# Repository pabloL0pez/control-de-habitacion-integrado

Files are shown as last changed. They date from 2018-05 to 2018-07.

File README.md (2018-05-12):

# Control de habitación integrado

## Hardware

* Modulo rfid: RFID-RC522 $60.45 x2
* Arduino nano
* Sensor de luz ldr
* Sensor de movimiento: Modulo PIR HC-SR501 $56.68
* Modulo wifi: esp8266 $108
* Boozer piezoelectrico
* Fotoresistencia LDR
* Sensor magnetico
* Pulsador
* tags rfid
* rele (para simular desbloqueo de puerta)

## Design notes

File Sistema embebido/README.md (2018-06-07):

# Control de habitación integrado - Arduino

## Hardware

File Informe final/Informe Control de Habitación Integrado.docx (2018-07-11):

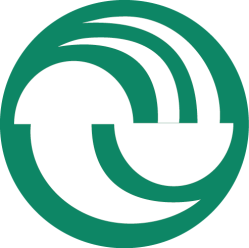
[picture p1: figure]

Universidad Nacional de La Matanza

Departamento de Ingeniería e Investigaciones Tecnológicas

Sistemas Operativos Avanzados

Trabajo Práctico

Sistemas Embebidos Android

Control de Habitación Integrado

Apellido y Nombre | DNI
Beckerman, Leandro | 34295624
López, Pablo Joel | 39154213
Fritz, Braian Nicolas | 38130321
De Diego, Brian Adrián | 36399037

# Descripción General

Este sistema permite la apertura de puertas a través de tarjetas magnéticas que al apoyarlas en un lector colocado al lado de cada puerta, verifica que la tarjeta esté autorizada para poder abrirla. Además, permite otras funcionalidades mediante una aplicación de celular como la apertura de puerta sin tarjeta, control de encendido, apagado e intensidad de luz de la misma, corroborar si hay gente dentro de ella y adicionalmente poder medir la cantidad de luz.

# Objetivo

El objetivo del Proyecto es la apertura de puertas a través de un módulo RFID, se realiza la validación de la clave de la tarjeta a través de un web service y desbloquea la misma. Una vez que se abren las puertas se captura un log de información de la persona que quiere ingresar al establecimiento. Paralelamente se puede controlar la luz de la habitación mediante una aplicación para Android, ver el estado de la habitación que se comunica con el mismo web service mediante JSON.

# Consideraciones

- Detectar cuando la puerta está abierta/cerrada.
- Detectar cuando hay individuos en la sala
- Si la puerta no se cierra o no está bien cerrada, entonces el sistema debe emitir un sonido de advertencia durante un determinado tiempo.
  - Si la puerta se cierra correctamente se apaga el sonido de advertencia.
  - Si durante ese tiempo no se cierra la puerta, entonces se apaga tal sonido. (Evitar que sea molesto)
- La persona puede encender o modificar (intensidad de luz) de las luces del establecimiento.
- Al fallar la identificación de la tarjeta N veces, se toma una advertencia (posible bloqueo).

Los fundamentos principales del Proyecto constan:

- Permitir el acceso a personas autorizadas hacía un lugar restringido. Guardar la información de las tarjetas (IDs) de las personas que ingresan al establecimiento.
- Identificación de intrusos.
- Aplicable a lugares donde hay un acceso restringido.

# Diagrama Físico

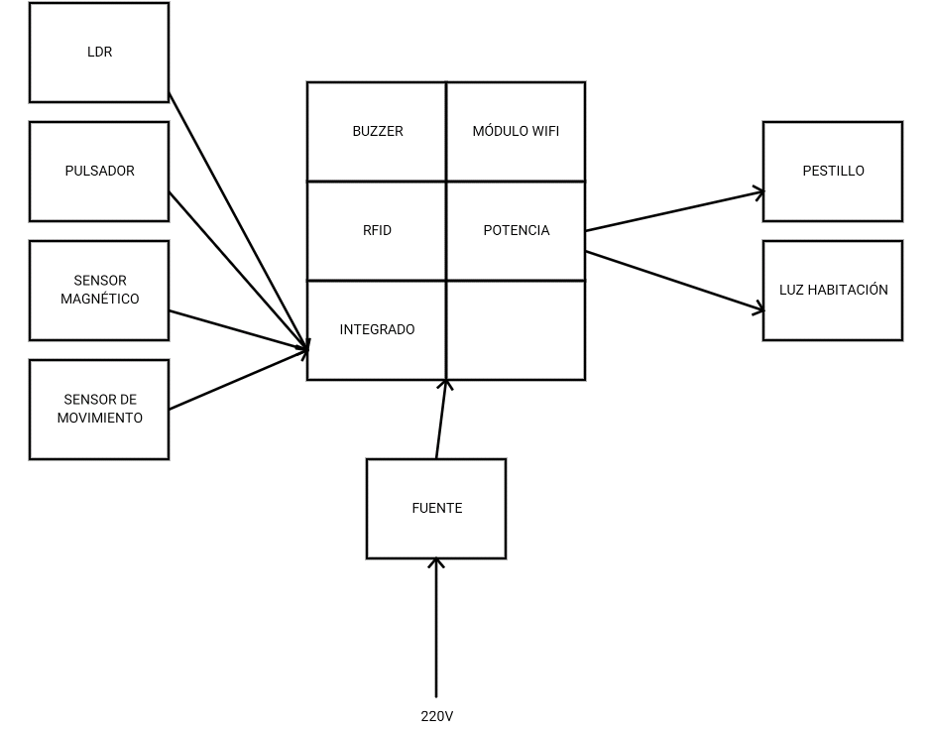
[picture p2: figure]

# Diagrama Lógico

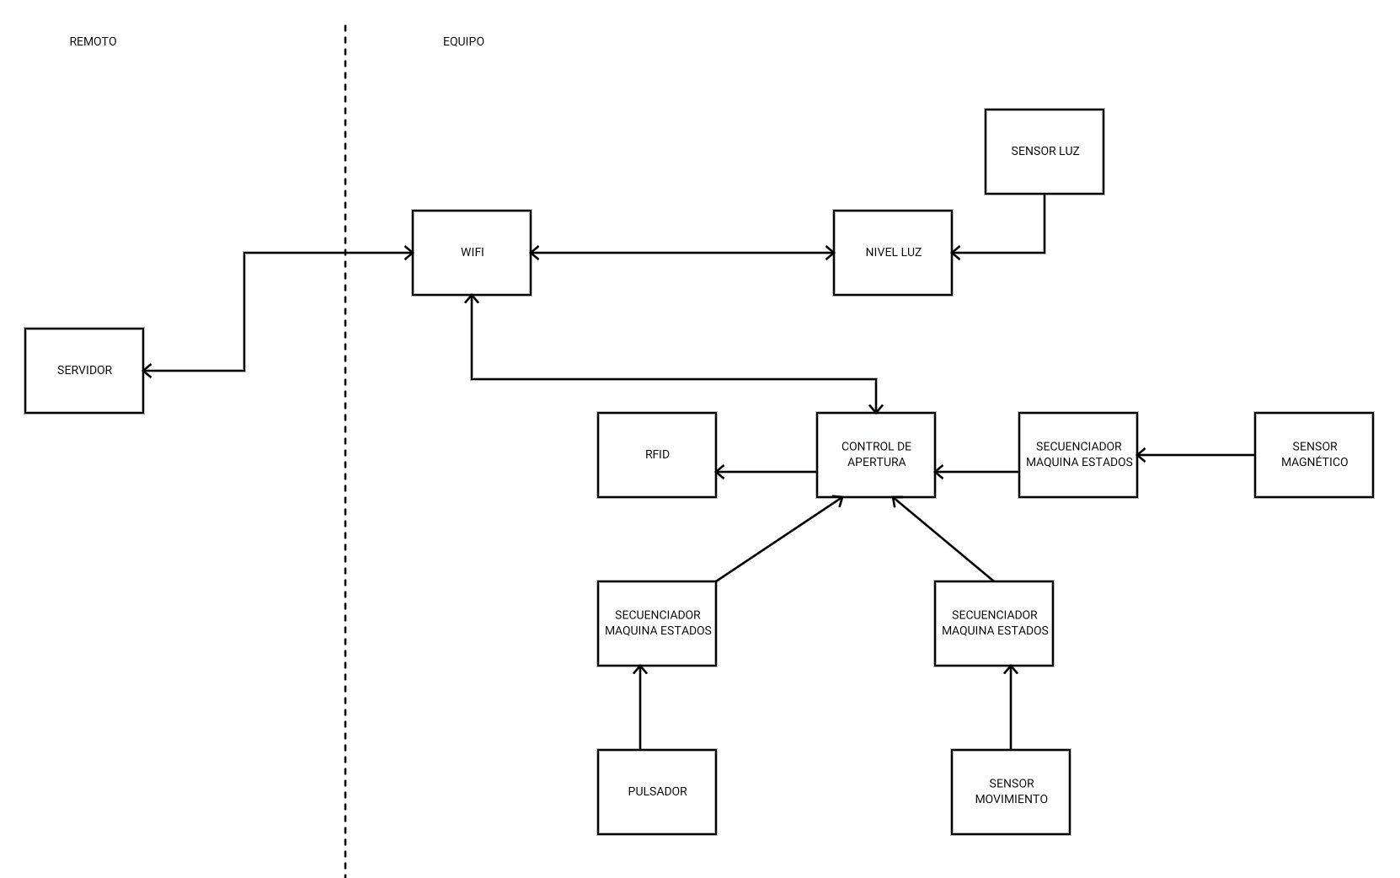
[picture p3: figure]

# Circuito Esquemático

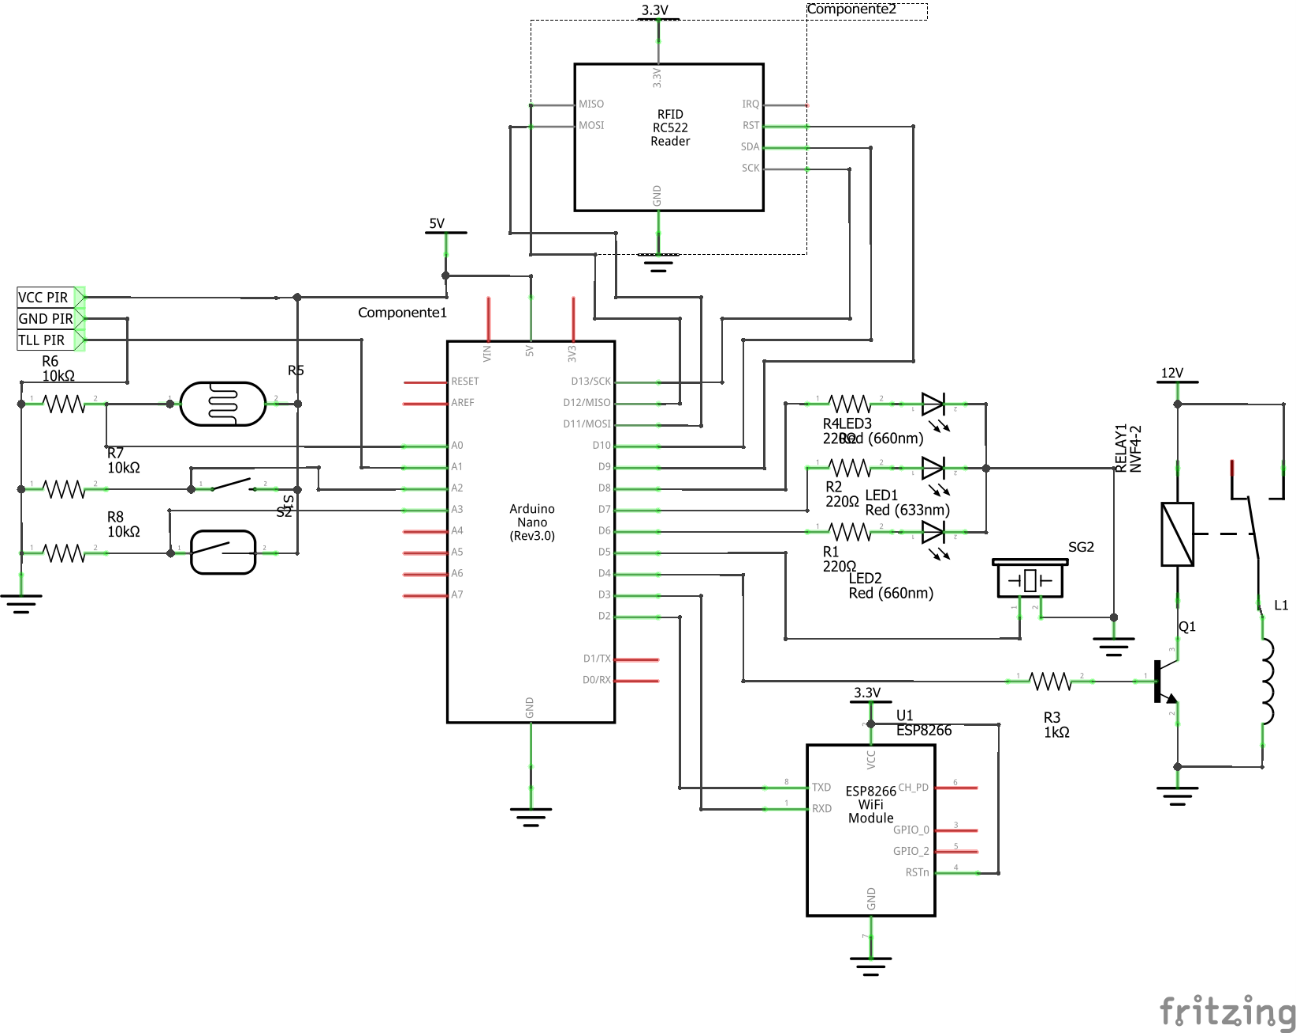
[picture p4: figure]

# Hardware utilizado

Módulo RFID-RC522 | Buzzer piezoeléctrico
Arduino NANO V3 | LEDs
Fotorresistor LDR | Sensor magnético
Modulo PIR HC-SR501 | Pulsador
Módulo WiFi ESP8266-01 | Tags RFID
Rele | Transitor NPN BC548
Pestillo eléctrico | 2 ProtoBoard de 150 puntos
Resistencias | Cables de Conexion

# Software utilizado

- Android Studio 2.3
- Arduino IDE 1.8.2
- Servidor Web NodeJS versión 8

# Tareas realizadas

1. Se realizo un diagrama de conexión y se procedio a conectar todos los componentes descritos en el hardware al Arduino
2. Se programo en Arduino IDE el sketch para automatizar el sistema y poder permitir la comunicación de la lógica de la habitación con el servidor mediante el modulo WiFi
3. Desarrollamos un web service en NodeJS para ser la interfaz entre el Arduino y la aplicación de celulares, además de ser el encargado de determinar cuando una tarjeta es válida o no
4. Desarrollamos una aplicación para Android con el fin de poder hacer desde ella un control total de todas las funciones del sistema, como la apertura de puerta sin tarjeta, control de intensidad lumínica de la habitación, ver registro de entradas y salidas, etc.

# Información técnica

## Módulo RFID RC522

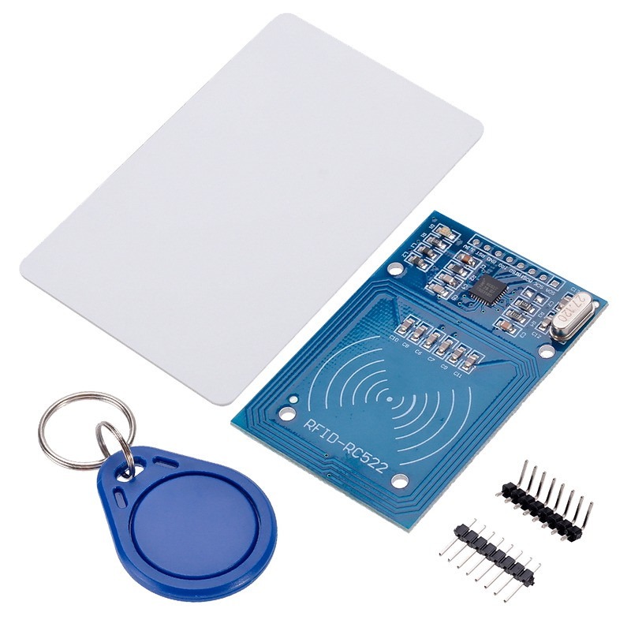
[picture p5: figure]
Resultado de imagen para tarjetas rfid

Su principio de funcionamiento consiste en pasar un TAG, cerca de un lector RFID, el TAG tiene la capacidad de enviar información al lector. Dicha información puede ser desde un simple código o todo un paquete de información guardo en la memoria del Tag.

Los TAGs viene en diferentes modelos, los más comunes son en tarjetas y en llaveros, pero también vienen como etiquetas adhesivas e incluso ya viene incrustados en algunos productos. Los Tags tienen internamente una antena y un microchip, encargado de realizar todo el proceso de comunicación, la energía lo obtiene de la señal de radiofrecuencia, que si bien la energía en la señal es pequeña, es suficiente para hacer trabajar el microchip, esto es la razón por la que es necesario acercarlos a una pequeña distancia generalmente menor a 10 cm.

## Buzzer piezoeléctrico

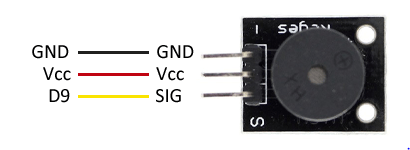
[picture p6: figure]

Los buzzer son transductores piezoeléctricos. Los materiales piezoeléctricos tienen la propiedad especial de variar su volumen al ser atravesados por corrientes eléctricas. Un buzzer aprovecha este fenómeno para hacer vibrar una membrana al atravesar el material piezoeléctrico con una señal eléctrica. Los buzzer son dispositivos pequeños y compactos, con alta durabilidad, y bajo consumo eléctrico.

## Arduino Nano V3

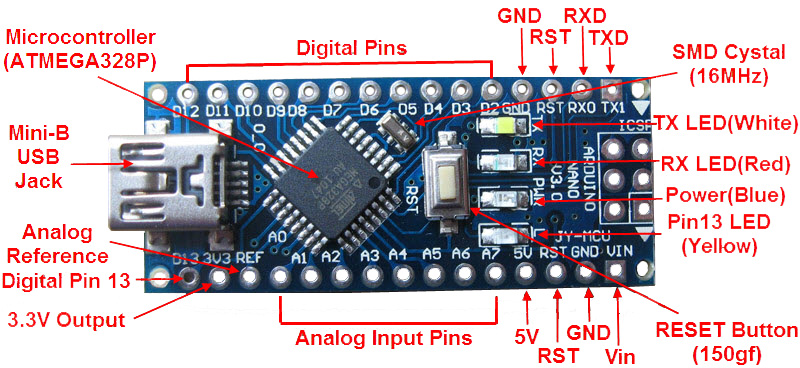
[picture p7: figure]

Este Arduino es la versión mas pequeña del Arduino uno. Basada en el Atmega328 SMD. Esta version esta pensada para usar en protoboard. las disposicion de sus pines facilitan la conexion de los componentes si necesidad de muchos cables. La otra gran ventaja por mas obvia que parezca esta en su tamao, durante algun tiempo fue la placa mas pequeña de todas, luego superada por el Arduino Micro(basada en el chip del leonardo) y el Arduino Mini Pro(basado tambien en el Atmega328).

## Sensor de movimiento PIR HC-SR501

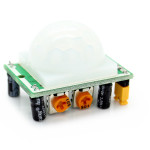
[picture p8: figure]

El módulo HC-SR501 tiene 3 pines de conexión +5v, OUT (3,3v) y GND, y dos resistencias variables de calibración (Ch1 y RL2).

Los detectores PIR (Passive Infrared) o Pasivo Infrarrojo, reaccionan sólo ante determinadas fuentes de energía tales como el calor del cuerpo humano o animales. Básicamente reciben la variación de las radiaciones infrarrojas del medio ambiente que cubre. Es llamado pasivo debido a que no emite radiaciones, sino que las recibe. Estos captan la presencia detectando la diferencia entre el calor emitido por el cuerpo humano y el espacio alrededor. Contiene un filtro llamado lente de Fresnel, que centra las señales infrarrojas sobre el elemento, si estas cambian, el amplificador cambia la salida para indicar un movimiento.

## Sensor Magnético de Apertura

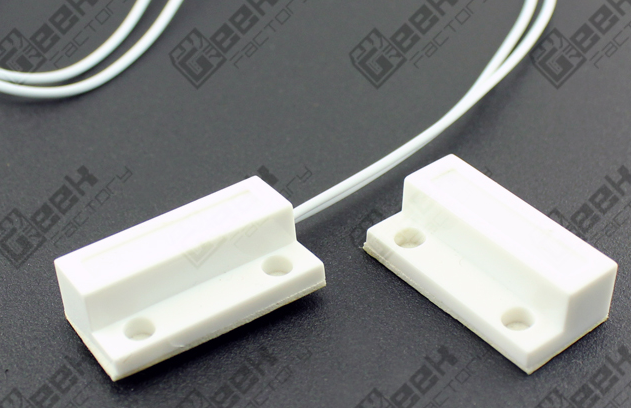
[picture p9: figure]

El Sensor magnético para ventanas y puertas consta de un imán y un reedswitch. El reedswitch es un interruptor de lengüeta que consiste en un par de contactos ferrosos encerrados al vacío dentro un tubo de vidrio. Cada contacto está sellado en los extremos opuestos del tubo de vidrio.

Al acercarse a un campo magnético, los contactos se unen cerrando un circuito eléctrico. La rigidez de los contactos hará que se separen al desaparecer el campo magnético. Para asegurar la durabilidad, la punta de los contactos tiene un baño de un metal precioso.

## Protoboard 150 puntos

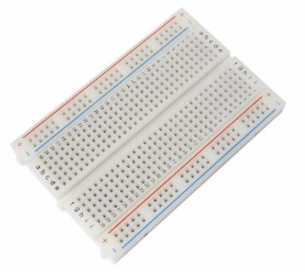
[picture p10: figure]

Utilizado para realizar prototipos rápidos de circuitos electrónicos.

## Relé

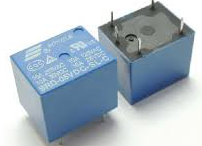
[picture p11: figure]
C:\Users\bfritz\AppData\Local\Microsoft\Windows\Temporary Internet Files\Content.MSO\4638F99D.tmp

El relé es un dispositivo electromagnético. Funciona como un interruptor controlado por un circuito eléctrico en el que, por medio de una bobina y un electroimán, se acciona un juego de uno o varios contactos que permiten abrir o cerrar otros circuitos eléctricos independientes.

## Modulo WiFi ESP8266

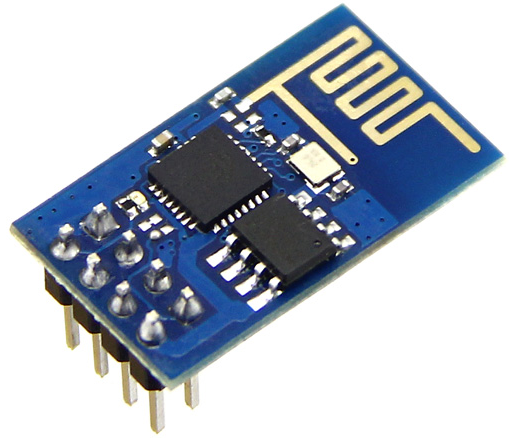
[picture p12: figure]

El ESP8266 es un chip Wi-Fi de bajo coste con pila TCP/IP completa y capacidad de MCU (Micro Controller Unit). La forma más simple de usar el módulo ESP8266 es comunicarse con él a través del puerto serie y manejarlo mediante los comandos AT que tiene en su firmware. Soporta IPv4 y los protocolos TCP/UDP/HTTP/FTP y no soporta HTTPS.

## Fotorresistor

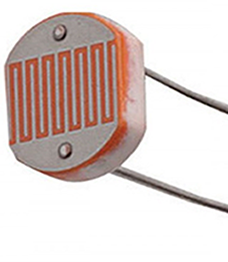
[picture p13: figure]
Resultado de imagen para ldr datasheet
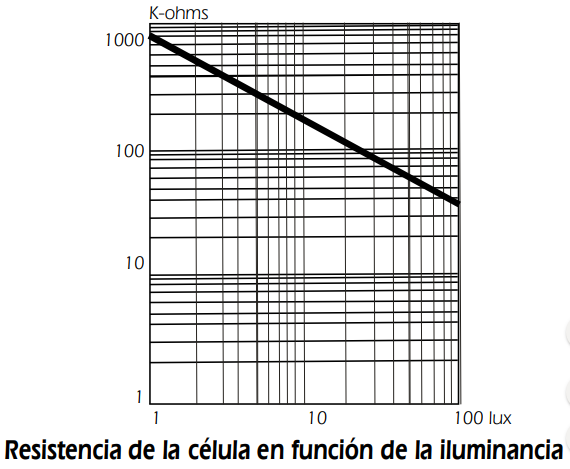
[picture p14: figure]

Un fotorresistor es un componente electrónico cuya resistencia disminuye con el aumento de intensidad de luz incidente. Está hecho de un semiconductor de alta resistencia como el sulfuro de cadmio. Si la luz que incide en el dispositivo es de alta frecuencia, los fotones son absorbidos por las elasticidades del semiconductor dando a los electrones la suficiente energía para saltar la banda de conducción. El electrón libre que resulta, y su hueco asociado, conducen la electricidad, de tal modo que disminuye la resistencia.

# Imágenes de la maqueta:

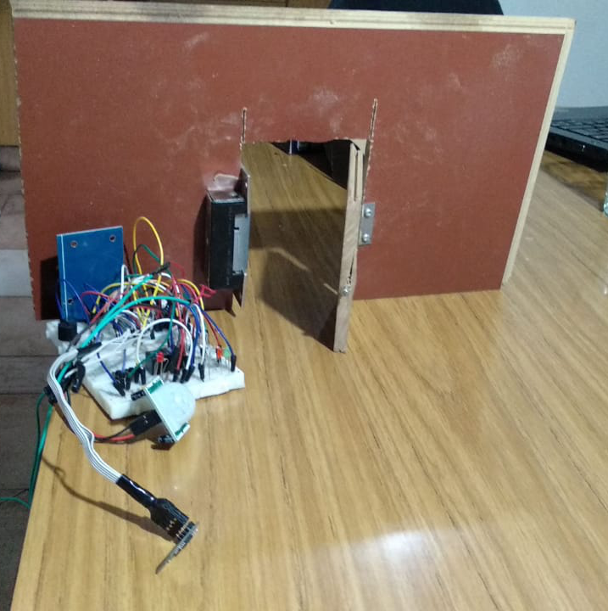
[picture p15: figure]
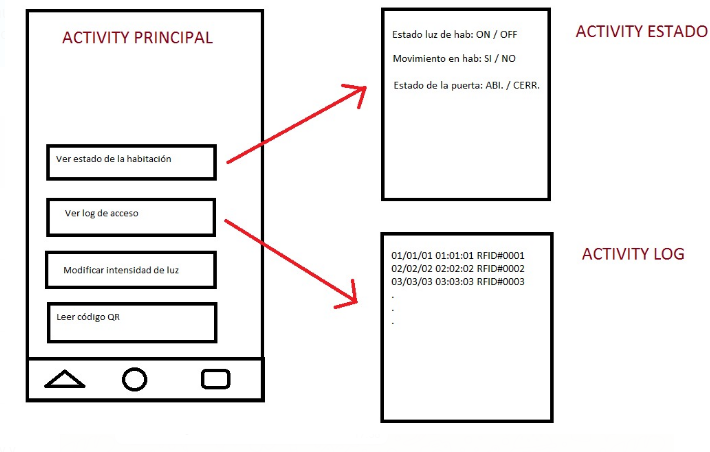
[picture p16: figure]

# Diagrama de la Aplicación de Android

Activity: Activity_main → Este Activity muestra las opciones que se pueden realizar dentro de la habitación. Tales opciones son:

- Ver Estado de la Habitación
- Ver log de acceso a la habitación
- Modificar Intensidad de la luz
- Leer código QR para ingresar a la habitación.

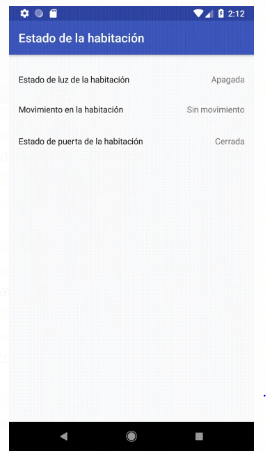
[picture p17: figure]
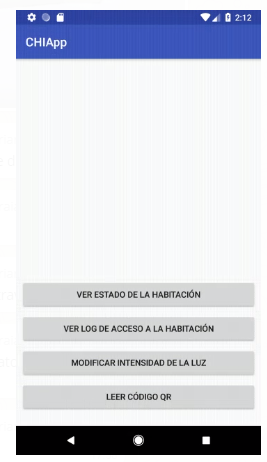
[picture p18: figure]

Estado de la habitación | Menú Principal

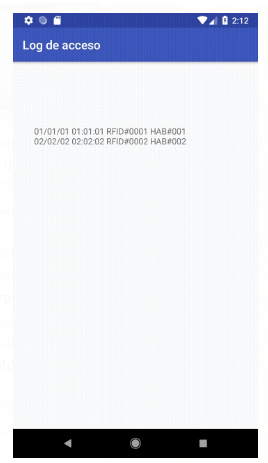
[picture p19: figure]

Ver Log de acceso

Control de Habitación IntegradoSistemas Operativos Avanzados

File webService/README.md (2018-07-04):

# WebService

### Configuracion

* Instalar nodejs: https://nodejs.org/es/download/package-manager/

### Ejecucion
Ejecutar los siguientes comandos en la terminal para poner en marcha el webservice

* npm install (solo la primera vez)
* npm start (para dar de alta el servidor)

### Endpoints

* GET /api/access :Obtiene los ids de las tarjetas que pueden acceder
* POST /api/access :Utilizado para la creacion de la tarjeta, enviar un json con el siguiente formato
```json
{
    "card": "[id de la card]"
}
```
* GET /api/logs :Se puede ver el log de acceso, se ve la referencia a la card y en que horario accedio
* POST /api/configs :Para crear el endpoint de luminosidad enviar el siguiente json
```json
{
    "label": "luminosidad",
    "value": "-1"
}
```
* GET /api/configs?conditions={"value": "luminosidad"} :Para obtener el valor de luminosidad (pensado para telefono)
* PUT /api/configs/[_id_de_label_luminosidad] : Enviando el siguiente json se puede modificar el valor de la luminosidad
```json
{
    "value": "[nivel de luminosidad]"
}
```
* GET /luminosidad (Para arduino)

RESPONSE
|-1| para apagado
|45| para los distintos niveles (el valor entre pipes es entre 0 y 100)

* GET /access/[cardId] :Dice si se puede acceder o no (Para Arduino)

RESPONSE
|0| para false
|1| para true

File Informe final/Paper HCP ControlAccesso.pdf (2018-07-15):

## Procesamiento HPC en Sistema de control de habitación integrado

Beckerman, Leandro Martín; López, Pablo Joel; De Diego, Brian Adrián; Fritz, Braian Nicolás

Universidad Nacional de La Matanza, Departamento de Ingeniería e Investigaciones Tecnológicas, Florencio Varela 1903 - San Justo, Argentina leobeckerman88@gmail.com; pablo.lopez3895@gmail.com; briandediego@gmail.com; braian.fritz@gmail.com

Resumen. El objetivo de esta investigación es de realizar el procesamiento de un gran volumen de datos generado por la implementación del sistema en diversos complejos de universidades por lo que será necesario poder manejar de forma simultánea el acceso a las habitaciones. Para poder realizar esto se propone la utlización de OpenMP para la explotación del paralelismo.

Palabras claves: HPC, BigData, Multicore, OpenMp, Server

### 1 Introducción

La investigación que se desarrolla en este documento está aplicada al Sistema de Control de Habitación Integrado. La problemática que se presenta es la del control de acceso de una gran cantidad de individuos de forma simultánea, por lo que un servidor podría saturarse o colapsar si este tuviera que manejar todas estas peticiones de forma secuencial, lo que podría provocar que, por ejemplo, el usuario que intente acceder primero a la habitación, se le otorgue el acceso último debido a las condiciones de carrera provocadas por el acceso simultáneo de una gran cantidad de usuarios.
Lo que se propone es la utilización de paralelismo para el procesamiento eficiente de dichas peticiones, mejorando el tiempo de respuesta del servidor mediante el modelo de programación OpenMP, ya que se utiliza un único servidor (memoria compartida), preferiendo OpenMP en ves de POSIX debido a que ha demostrado una significante diferencia en performance además de ser mas portable, ser mas sensillo de implementar y proporcionar seguridad entre los hilos. [1]

### 2 Desarrollo

En principio, es necesario explicar el funcionamiento de nuestro sistema de control de acceso. Su funcionamiento consiste en la utilización de un sistema embebido que recibe una lectura a través de un módulo RFID y luego de i interpretarla los datos viajan por comunicación Wi-Fi desde el embebido al servidor central de proceso. Una vez allí se evaluará si dicho acceso está permitido o no, brindando una respuesta acorde al embebido el cual permitirá o no el acceso del usuario a la habitación. Debido a que una institución académica posee una cantidad aproximada de 650 habitaciones entre los cuales podemos nombrar aulas, laboratorios y centros de control; se pueden presentar una gran cantidad de peticiones simultáneas al servidor, como se mencionó anteriormente lo que provocara demoras o hasta incluso fallos en la apertura de las puertas. Para el desarrollo de esta tecnología es imperativo contar con un sistema multiprocesador para la paralelización de los distintos procesos que van a controlar el acceso de los usuarios. Un proceso inicial empezara la ejecución, que se conoce como región serie, y luego se utilizarán distintos algoritmos que encolarán a las peticiones de los usuarios y las distribuirán entre distintos procesos a través de las directivas de fork/join proporcionadas por el modelo de programación OpenMP Esta región se conoce como región paralela. [2] [3] También es necesario contar con una base de datos que pueda trabajar de forma paralela.

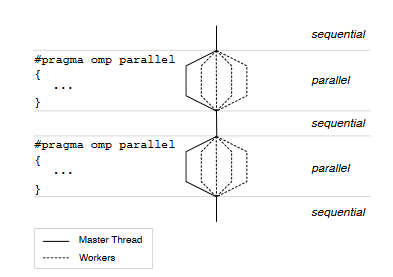
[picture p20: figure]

3 Explicación del algoritmo.
Void main() {
Event,on(“nuevo usuario”, function(user) {

pushUsuarioEnCola(user);
responderAccesoUsuarioConcurrente (user); });
}

Function responderAccesoUsuarioConcurrente (user) { // Comienzo de parte de codigo OpenMP if(isServerSaturado() && fork()) { respuestaUsuario(getUsuariosDeCola(users)) // FIN de parte de codigo OpenMP
} else {

If(tieneAcceso(users[user])) { Send(“valid user”)
} else {
Send(“invalid user”)
}
}
}

Function respuestaUsuario(users) {
For(int i = 0; i < users.length; i++) { If(tieneAcceso(users[user])) { Send(“valid user”)
} else {
Send(“invalid user”)
}
}
}

### 4 Pruebas que pueden realizarse

Una serie de pruebas que se pueden realizar es la prueba de tiempo de respuesta, con solamente una habitación y luego realizar la misma prueba con 650 habitaciones y evaluar la diferencia utilizando OpenMP en ambas pruebas.
Realizar la prueba con OpenMP y sin OpenMP en un entorno real para conocer la verdadera diferencia entre aplicar paralelismo o no.
Realizar un caso de fatiga que involucre a todos los embebidos a la vez, realicen las solicitudes de acceso constantemente durante un lapso de 20 segundos y que el sistema responda de forma esperada.

### 5 Conclusiones

En base a la investigación en el proyecto pudimos observar que en un entorno académico existen una gran cantidad de habitaciones o aulas en las que se puede aplicar el sistema de control de acceso.
Cuando hay un gran volumen de datos a procesar, OpenMP mejora los tiempos de ejecución del servidor, proporcionando una mejora en el tiempo de respuesta que recibe el usuario al intentar acceder una habitación utilizando el sistema de control de acceso, siendo esto uno de los principales requerimientos para una excelente experiencia de usuario.
Sin embargo, por mas que se paralelicen las peticiones y con ellas las consultas a la base de datos, aun queda mucho por mejorar, debido a que los tiempos de respuesta de un acceso a almacenamiento tradicional siempre sera el eslabón mas lento de la cadena. Esto sin embargo podría ser optimizado utilizando discos de estado solido en vez de discos duros mecánicos, obeniendo notorias mejoras en el tiempo de respuesta. Por otro lado se podría levantar toda la información necesaria para el sistema en memoria, y paralelizar las comprobaciones lógicas, evitando así el acceso a un medio de almacenamiento. Sin embargo es algo que queda fuera de este documento.
Por lo que concluimos que OpenMP es una buena opción para usarlo en nuestro proyecto como lo hemos descripto o para sus posibles mejoras y aplicarlo a entornos más complejos como edificios urbanos, centros médicos y instituciones académicas.

### 6 Referencias

1. OpenMP versus Threading in C/C++ (2014)
2. Measuring synchronization and cheduling overheads in openMp (2016)
3. Paralel computing using openMp (2017)

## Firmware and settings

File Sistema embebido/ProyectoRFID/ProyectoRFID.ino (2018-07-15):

/*
Control de Acceso

Pinout:
D0:   -----
D1:   -----
D2:   RX
D3:   TX  
D4:   Desbloqueo Puerta 
D5:   Sirena
D6:   Luz Habitacion
D7:   Luz Verde
D8:   Luz Roja
D9:   Reset RC522
D10:  SS (SDA) RC522
D11:  MOSI RC522
D12:  MISO RC522
D13:  SCK
A0:   LDR
A1:   PIR
A2:   BUTTON
A3:   Magnetico
A4:   Testigo Pir
A5:   -----
A6:   -----
A7:   -----
*/


#include "funciones.h"

#define SSIDNAME "SOA-ACCESO"
#define PASSWORD "soa123456"

MFRC522 mfrc522(SS_PIN, RST_PIN); //Creamos el objeto para el RC522

SoftwareSerial softSerial(2, 3); // RX | TX
ESP8266 wifi(softSerial);



bool sirenaSonando = false;
bool puertaAbierta = false;
bool puertaDesbloqueada = false;
// array con las acciones externas recividas. si es negativo no hago nada
//accionesExternas[0] -> Desbloqueo de puerta
//accionesExternas[1] -> Luz habitacion
//int accionesExternas[] = {-1, -1}; 
int accionesExternas[] = {-1, -1}; 
unsigned long doorUnlockMillis = 0;
unsigned long actionReciveMillis = 3000;
//unsigned long sensorSendMillis = 3000;
unsigned long currentMillis = 0;
byte luzPorciento = 0;

void setup() {
  pinMode(DOOR_OUT,OUTPUT);
  pinMode(ALARM_OUT,OUTPUT);
  pinMode(LED_LIGHT_OUT,OUTPUT);
  pinMode(LED_GREEN_OUT,OUTPUT);
  pinMode(LED_RED_OUT,OUTPUT);
  pinMode(LED_PIR_OUT,OUTPUT); // PIR Testigo

  pinMode(PIR_IN,INPUT);
  pinMode(LDR_IN,INPUT);
  pinMode(BUTTON_IN,INPUT);
  pinMode(DOOR_IN,INPUT);

  
  // put your setup code here, to run once:
  SPI.begin();        //Iniciamos el Bus SPI
  mfrc522.PCD_Init(); // Iniciamos  el MFRC522
   softSerial.begin(9600);
  Serial.begin(9600);
/*
   if (wifi.setOprToStationSoftAP()) {
      Serial.print("to station + softap ok\r\n");
   }
   else {
      Serial.print("to station + softap err\r\n");
   }
 
   if (wifi.joinAP(SSIDNAME, PASSWORD)) {
      Serial.print("Join AP success\r\n");

   }
   else {
      Serial.print("Join AP failure\r\n");
   }
 
   if (wifi.disableMUX()) {
      Serial.print("single ok\r\n");
   }
   else {
      Serial.print("single err\r\n");
   }
  */
   delay(5000);
   Serial.print(F("setup end\r\n"));
}

void loop() {
  digitalWrite(LED_PIR_OUT, digitalRead(PIR_IN));
  bool lectPuerta = digitalRead(DOOR_IN);
  bool lectBotonPuerta = digitalRead(BUTTON_IN);
  currentMillis = millis();
  // Leo si tengo alguna tarjeta para leer
  //Serial.println("Preparo para la lectura");
  String lectura = leerRFID(mfrc522);
  if(lectura.length() > 1){
    
    Serial.print(F("Tarjeta Leida\r\n"));
    if(consultarRFID(lectura)){
     // Serial.print("Debo abrir la puerta\r\n");      
      //Serial.println(lectura);
      desbloquearPuerta();
      
    }else{
      //Serial.print("NO debo abrir la puerta\r\n");
    }
  }
delay(200);
  if(lectBotonPuerta){
    desbloquearPuerta();
  }

  if(pasoTiempoRecibirAcciones()){ //paso el tiempo para revisar las acciones
    actionReciveMillis = millis();
    if(consultarAccionesRemotas(accionesExternas)){
      if(accionesExternas[0] == 1 && !puertaDesbloqueada){
        desbloquearPuerta(); 
      }
      if(accionesExternas[1]> -1 ){
        luzPorciento = (byte)accionesExternas[1];
        manejarLuz(luzPorciento);
      }
    }
    leerSensores();
  }
/*
  if(pasoTiempoEnviarSensores()){ //paso el tiempo para enviar informacion de sensores
    sensorSendMillis = currentMillis;
//    leerSensores();
  }
*/


  if(puertaDesbloqueada){
    
    if(!puertaAbierta){
      if(lectPuerta){ // si justo se abrio la puerta cuando se penso que estaba cerrada
        puertaAbierta = true;
        bloquearPuerta();
        
      }
    } 
    if(pasoTiempoDoorUnlock()){ // si despues de un tiempo de estar desbloqueada la puerta la bloqueamos
        bloquearPuerta();      
    }
    
  }
  if(lectPuerta){ // si la puerta esta actualmente abierta
  
  if(!sirenaSonando && pasoTiempoDoorUnlock()){ //y despues de un tiempo de estar la puerta desbloqueada y la alarma no esta sonando hacemos sonar la alarma
    //suena alarma
    digitalWrite(ALARM_OUT, HIGH);
    sirenaSonando = true;
  }

  } else{
    if(sirenaSonando){ //y la sirena suena apagamos la puerta
      digitalWrite(ALARM_OUT, LOW);
      sirenaSonando = false;
      puertaAbierta = false;
    }else{
      puertaAbierta = false;
    }
  }

  

  
  
}

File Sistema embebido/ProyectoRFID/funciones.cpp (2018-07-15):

#include "funciones.h"


#define HOST_NAME "192.168.1.37"
#define HOST_PORT 80

uint8_t buffer[700] = { 0 };

void desbloquearPuerta(){
  Serial.print(F("!!!!!!!!!!Puerta Desbloqueada!!!!!!!!!!!!!!!!1\r\n"));
  digitalWrite(DOOR_OUT, HIGH);
  doorUnlockMillis = currentMillis;
  puertaDesbloqueada = true;
}

bool manejarLuz(byte porcentaje){
  if(porcentaje == 0){
    analogWrite(LED_LIGHT_OUT, 0);
    return false;
  }
  analogWrite(LED_LIGHT_OUT, (porcentaje*255)/100);
}

void bloquearPuerta(){
  digitalWrite(DOOR_OUT, LOW);
  puertaDesbloqueada = false;
}

bool pasoTiempoDoorUnlock(){
  return currentMillis - doorUnlockMillis > TIME_INTERVAL_UNLOCK;
}


bool pasoTiempoEnviarSensores(){
  //return currentMillis - sensorSendMillis > TIME_INTERVAL_INFO;
  return millis() - actionReciveMillis > TIME_INTERVAL_ACTION;
}

bool pasoTiempoRecibirAcciones(){
  return (currentMillis - actionReciveMillis) > TIME_INTERVAL_ACTION;
}

String leerRFID(MFRC522 mfrc522){
  String retorno = F("");
  if ( mfrc522.PICC_IsNewCardPresent()) 
        {  
      //Seleccionamos una tarjeta
            if ( mfrc522.PICC_ReadCardSerial()) 
            {
                  //Serial.println("Se detecto una tarjeta");
                  // Enviamos serialemente su UID
                  //Serial.print("Card UID:");
                  for (byte i = 0; i < mfrc522.uid.size; i++) {
                          //Serial.print(mfrc522.uid.uidByte[i] < 0x10 ? " 0" : " ");
                          //Serial.print(mfrc522.uid.uidByte[i], HEX);
                          retorno = String(retorno + String(mfrc522.uid.uidByte[i], HEX));   
                  } 
                  //Serial.println();
                  // Terminamos la lectura de la tarjeta  actual
                  mfrc522.PICC_HaltA();         
            }      
  }
  return retorno;
}

bool consultarRFID(String idTarjeta){
  
  String request = String("GET /arduino/"+idTarjeta+"/ HTTP/1.1\r\nHost: 192.168.1.37\r\nConnection: close\r\n\r\n");
  int retorno = sendWiFiRequest(request);
//  Serial.println("termino consultar RFID");
  if(retorno == 1)
    return true;
  return false;

}


bool consultarAccionesRemotas(int accionesExternas[2]){
int retorno =-1;
  //return true;
  //consulto por abrir la puerta
  Serial.print(F("Debo abrir puerta\r\n"));
  retorno = sendWiFiRequest( F("GET /arduino/abrirpuerta/ HTTP/1.1\r\nHost: 192.168.1.37\r\nConnection: close\r\n\r\n"));
  //Serial.println("termino consultar si abre la puerta");
  if(retorno < 0){
    accionesExternas[0] = -1;
  }
  accionesExternas[0] = retorno;
  //delay(300);
  
  
  
  //consulto por la luz
Serial.print(F("Debo encender la luz\r\n"));
  retorno = sendWiFiRequest(F("GET /arduino/luminosidad/ HTTP/1.1\r\nHost: 192.168.1.37\r\nConnection: close\r\n\r\n"));
  if(retorno < 0){
    accionesExternas[1] = -1;
  }
  accionesExternas[1] = retorno;

  return true;
}

int sendWiFiRequest(String request){
  
    String retorno = "";
  if (wifi.createTCP(HOST_NAME, HOST_PORT)) {
      //Serial.print("create tcp ok\r\n");
   }
   else {
      Serial.print(F("create tcp err\r\n"));
      //Serial.print(request);
      return false;
   }

   wifi.send((const uint8_t*)request.c_str(), request.length());
 
   uint32_t len = wifi.recv(buffer, sizeof(buffer), 2000);
   
   if (len > 0) 
   {
      //Serial.print("Received:\r\n");
      for (uint32_t i = 0; i < len; i++) 
      {
         char c = (char)buffer[i];
         //Serial.print(c);
         if (c == '|')
         {
            for (uint32_t j = i + 1; j < len; j++)
            {
               c = (char)buffer[j];
               if (c == '|') break;
               retorno = String(retorno + String(c));;
            }
            break;
         }
      }
      if(retorno == "")
        return -1000;
      return retorno.toInt();
      
}
return -1000; // hubo un problema

}

void leerSensores(){
  Serial.print(F("Voy a leer sensores\r\n"));
  String request = String("GET /sensores/"+String(analogRead(LDR_IN))+"/"+digitalRead(PIR_IN)+"/"+luzPorciento+"/ HTTP/1.1\r\nHost: 192.168.1.37\r\nConnection: close\r\n\r\n");
  int retorno = sendWiFiRequest(request);
}

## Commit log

2018-04-26 Estructura de carpetas
2018-05-08 Arranco codigo de desbloqueo/apertura de la puerta
2018-05-08 Pongo un commit mas para que parezca que trabajé un montón
2018-05-10 codigo base para webservice
2018-05-12 chequeo de acceso por array
2018-06-04 Empezando app de Android
2018-06-04 Se inicializan sensores, hay que hacer los métodos de cada sensor
2018-06-04 Se agregan activitys de estado y log (se pueden mejorar)
2018-06-04 Se implementa detección de sacudidas con acelerómetro
2018-06-04 Se leen datos del sensor de proximidad
2018-06-04 Cambio el boton de luz por un switch porque anda re mal sino
2018-06-04 Se definen porcentajes de luminosidad en base a la orientacion del terminal
2018-06-07 Se agrega lectura de código QR
2018-06-07 Pongo textView para ver el valor del código QR
2018-06-07 Inicio del proyecto
    Se removio el inicio anterior y se empezo uno nuevo. Se definieron algunas funciones basicas y agregue la libreria para la comunicacion RFID.
2018-06-07 PinOut Definitivo
    Se cambio el pinout provisorio, por el definitivo para el proyecto.
2018-06-14 Funciones Agregadas
    Arme mas la estructura principal de la aplicacion sin escribir la implementacion de las funciones
2018-07-04 añadido soporte para db
2018-07-04 añadido soporte para cambio de luminosidad, entradas de readme actualizadas
2018-07-04 Agregado luminosidad para arduino
2018-07-05 adaptaciones de urls y respuestas para arduino
2018-07-09 Correccion JSON y Correccion URL Arduino
2018-07-11 actualizacion de documentacion
2018-07-11 arreglado pseudocodigo openmp y agregada descripcion indicando el porque se usa openmp
2018-07-11 Correccion de Informe
2018-07-15 arreglolos de subida de datos al server desde android
2018-07-15 Implementacion de log y estado de hab. en app
2018-07-18 fixes de ultimo momento
